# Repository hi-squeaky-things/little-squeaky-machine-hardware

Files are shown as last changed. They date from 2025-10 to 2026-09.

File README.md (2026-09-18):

```
 ⡇ ⡇⢹⠁⢹⠁⡇ ⣏⡉ ⢎⡑⡎⢱⡇⢸⣏⡉⣎⣱⣇⠜⢇⢸ ⡷⢾⣎⣱⡎⠑⣇⣸⡇⡷⣸⣏⡉
 ⠧⠤⠇⠸ ⠸ ⠧⠤⠧⠤ ⠢⠜⠣⠪⠣⠜⠧⠤⠇⠸⠇⠱ ⠇ ⠇⠸⠇⠸⠣⠔⠇⠸⠇⠇⠹⠧⠤
```
[][cc-by-nc-sa]

The Little Squeaky Machine is a hardware reference platform for the [Little Weirdo Software Synthesizer](https://github.com/hi-squeaky-things/little-weirdo). 

Our first project is launching soon: our LttL Squeaky Machine! Put yourself on the list to get notified when we are ready to ship. 

[Join the waitinglist](https://www.hi-squeaky-things.nl/waiting-list)

[cc-by-nc-sa]: https://creativecommons.org/licenses/by-nc-sa/4.0/
[cc-by-nc-sa-image]: https://licensebuttons.net/l/by-nc-sa/4.0/88x31.png
[cc-by-nc-sa-shield]: https://img.shields.io/badge/License-CC%20BY--NC--SA%204.0-lightgrey.svg

> [!CAUTION]
> This project is actively being developed with frequent breaking changes. Wires may shift, features are incomplete, and stability is not guaranteed. Use at your own risk and expect regular updates that might require SW/HW adjustments. Have fun!

> [!IMPORTANT]
> **Hi Squeaky Things** can happen at any time. _Little Squeaky Machine_ is ready to squeak, squuuueak, squeeeeeaak, squeaaaaaaaaak and drop some deep body shaking basses!

## Little Squeaky Machine Hardware

The hardware is designed using EasyEDA. 

### Revision 3.0 

We are iteration on revision 3.0. Soon to be released. 



> [!CAUTION]
Small batch of this revision is fabricated. Use the schematics and layouts at your own risk because the new design is not fully tested yet. We are testing this revision with different types of key switches and caps and color. 

Rendered versions:

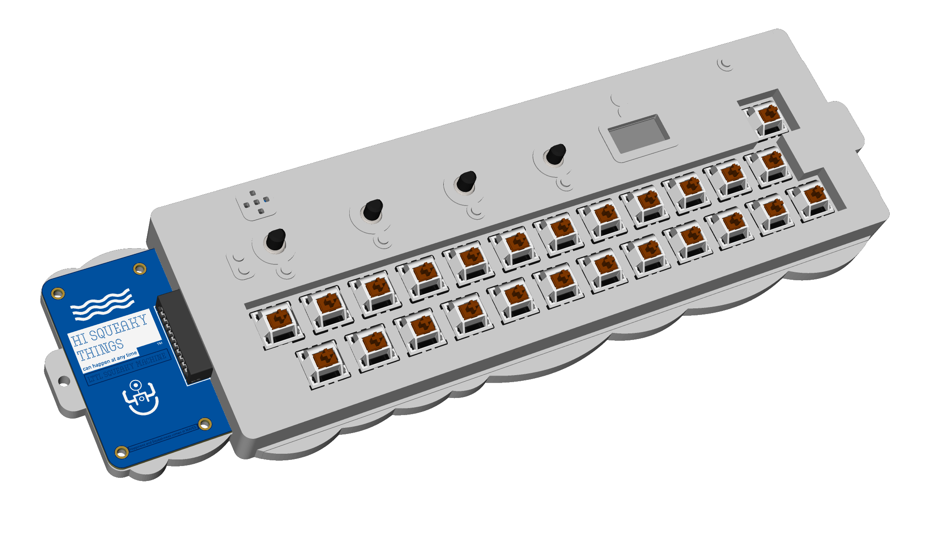
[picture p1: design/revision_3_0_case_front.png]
case front revision 3.0 with casing

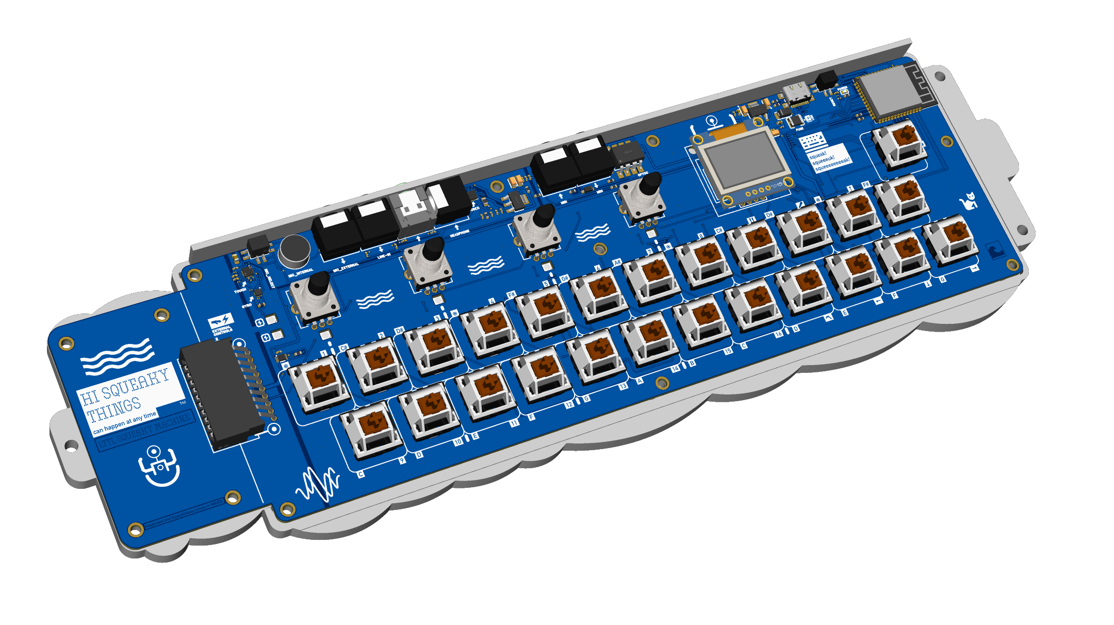
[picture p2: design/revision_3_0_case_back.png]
case back revision 3.0 with casing


- [Specification and capabilities](design/specs.md)
- [Pin layout of the ESP32S3 based MCU](design/pinout.md)
- [Fabrication files](fabrication)

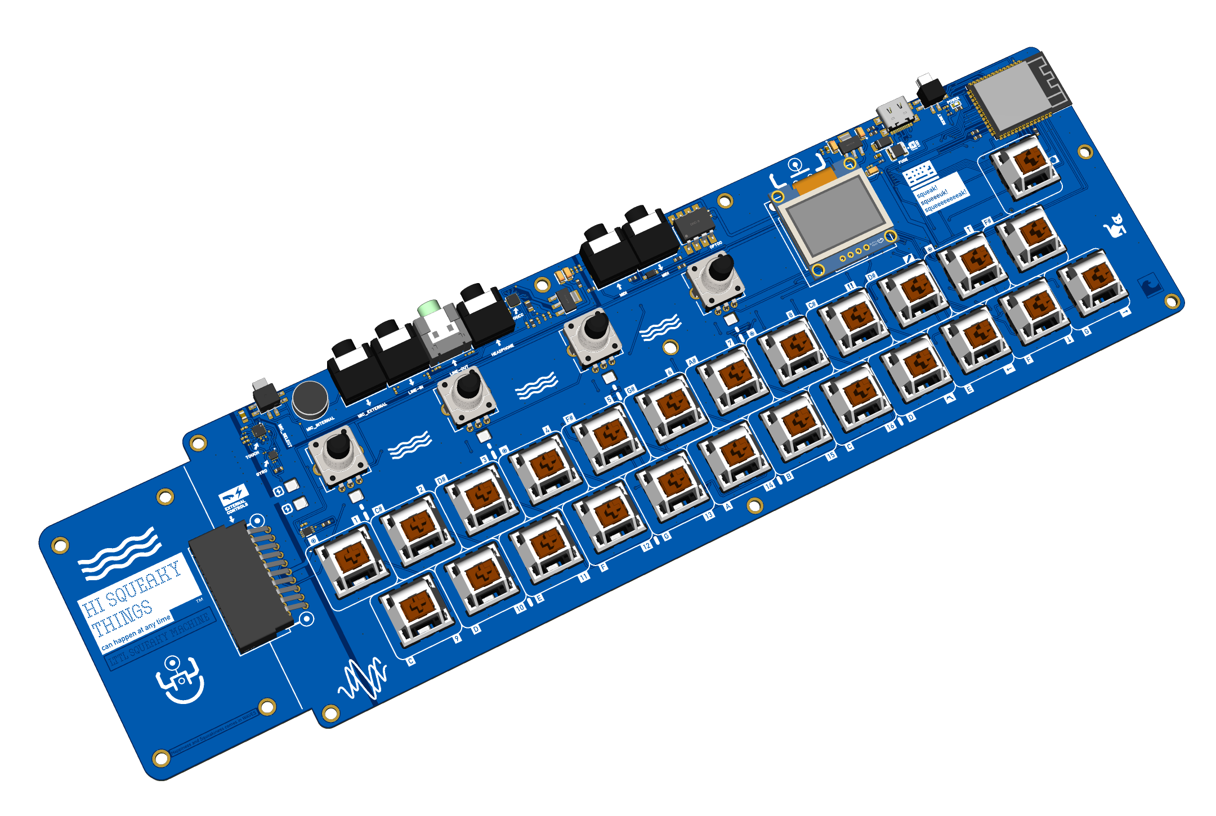
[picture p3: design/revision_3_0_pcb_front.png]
front pcb revision 2.0 pcb


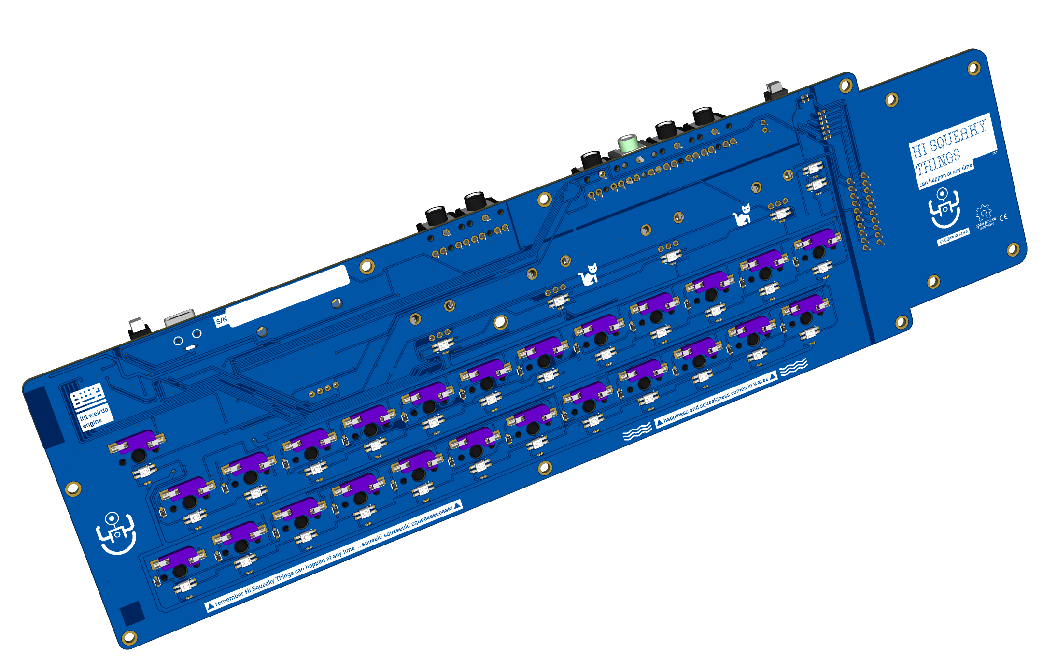
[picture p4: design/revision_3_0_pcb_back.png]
back pcb revision 2.0 pcb back


### Revision 2.0 

This is the first production ready hardware running a firmware using [Little Weirdo Software Synthesizer](https://github.com/hi-squeaky-things/little-weirdo) for sound synthesis. 

> [!CAUTION]
Small batch of this revision is fabricated. Use the schematics and layouts at your own risk because the new design is not fully tested yet. We are testing this revision with different types of key switches and caps and color. 

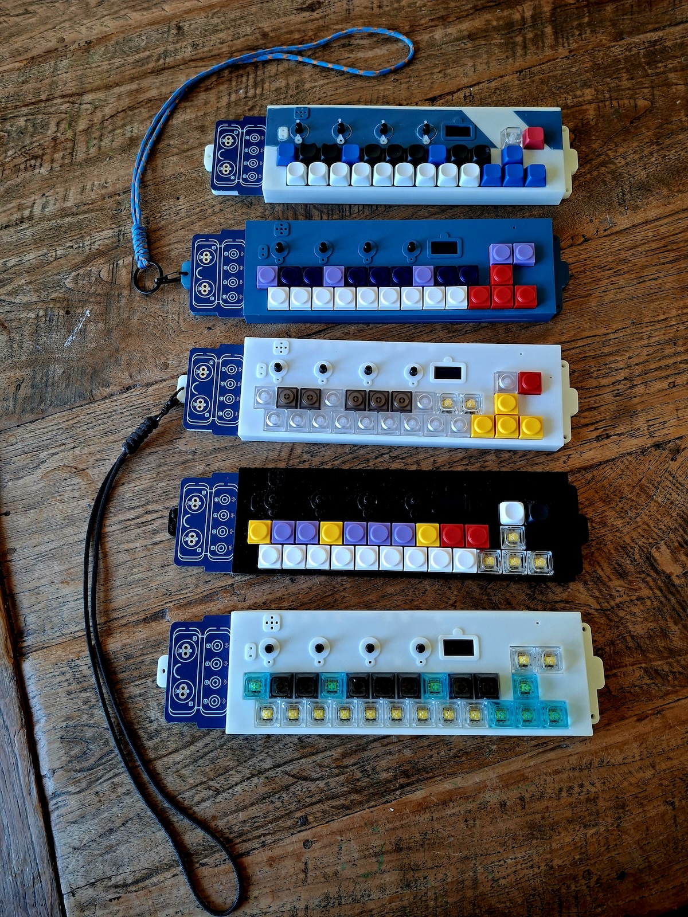
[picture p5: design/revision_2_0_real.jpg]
result assembly revision 2.0 real life


Rendered versions:

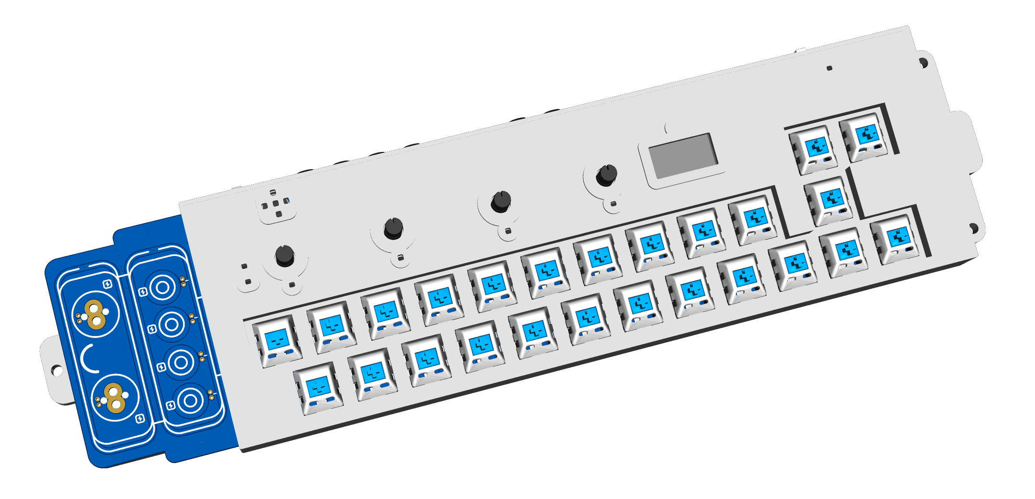
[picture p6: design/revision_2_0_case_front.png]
case front revision 2.0 with casing

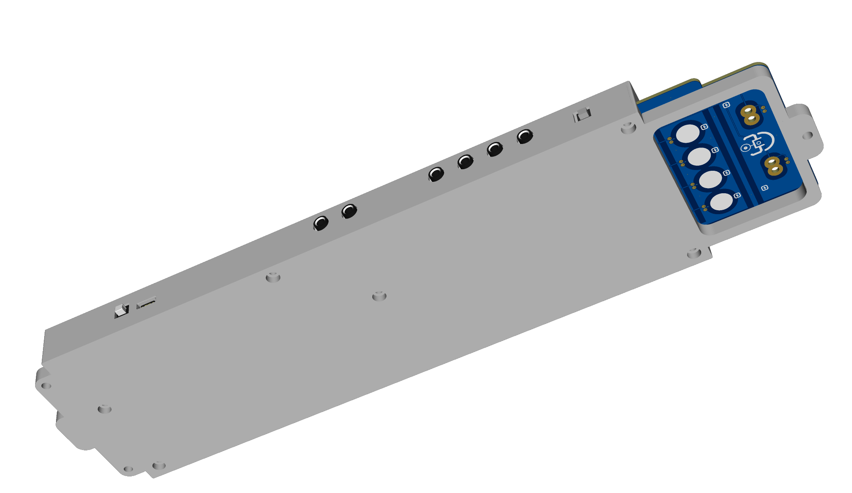
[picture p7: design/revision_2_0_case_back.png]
case back revision 2.0 with casing

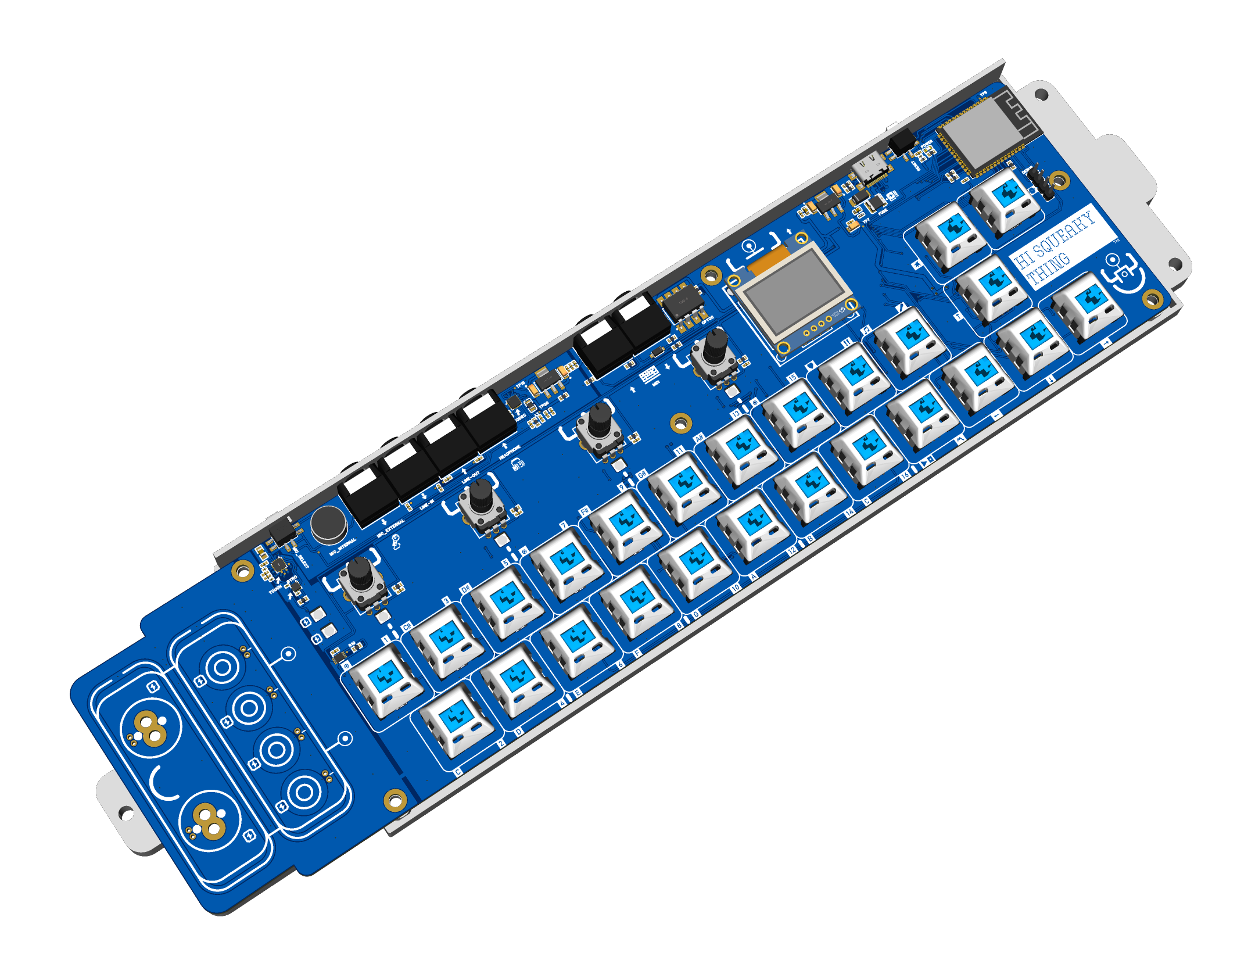
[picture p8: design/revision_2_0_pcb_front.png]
front pcb revision 2.0 pcb

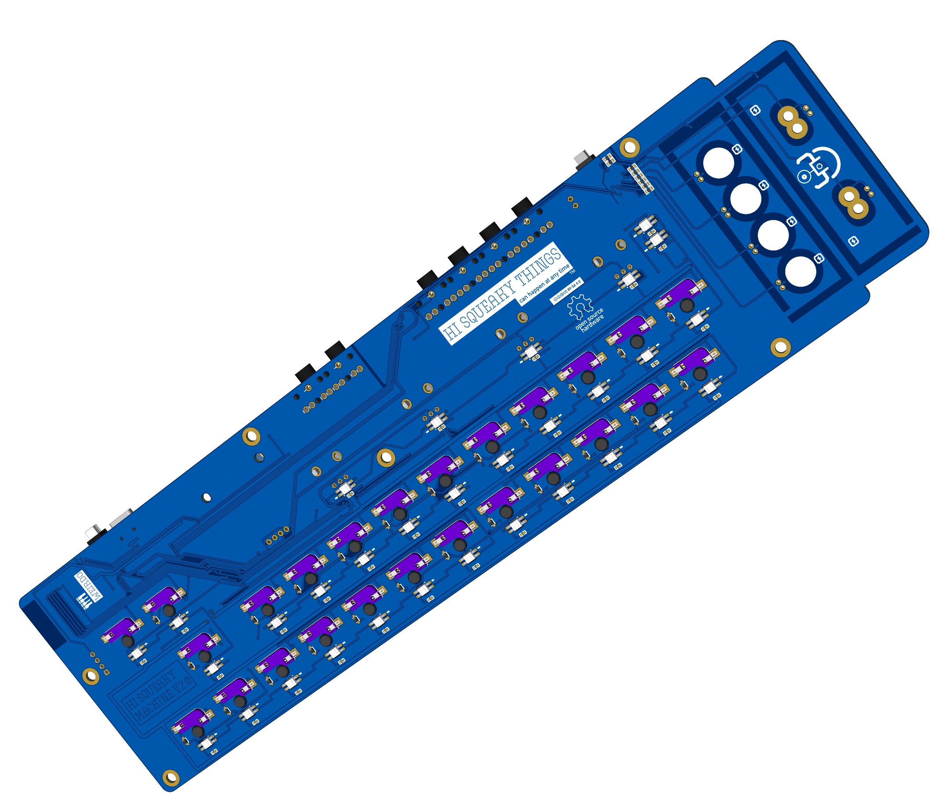
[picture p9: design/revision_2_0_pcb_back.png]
back pcb revision 2.0 pcb back


### Revision 1.0

This is the first prototype we created and running a firmware using [Little Weirdo Software Synthesizer](https://github.com/hi-squeaky-things/little-weirdo) for sound synthesis. This revision was only for a proof-of-concept some features and not for production use.

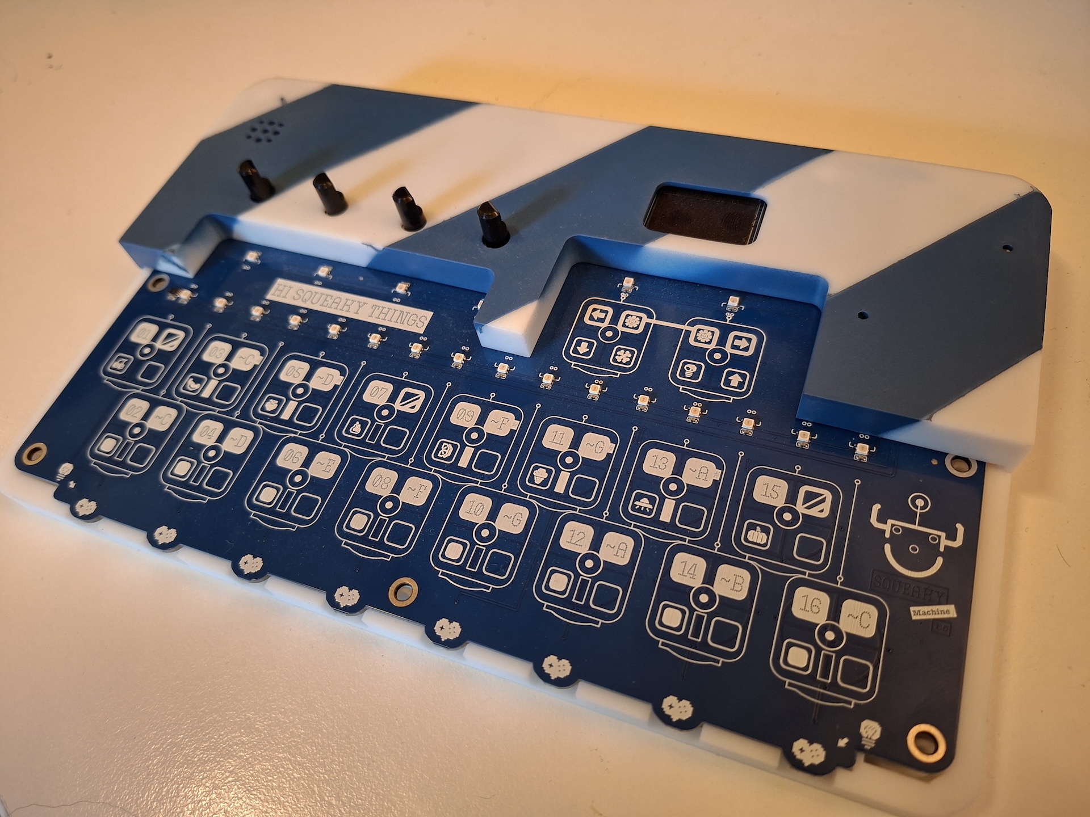
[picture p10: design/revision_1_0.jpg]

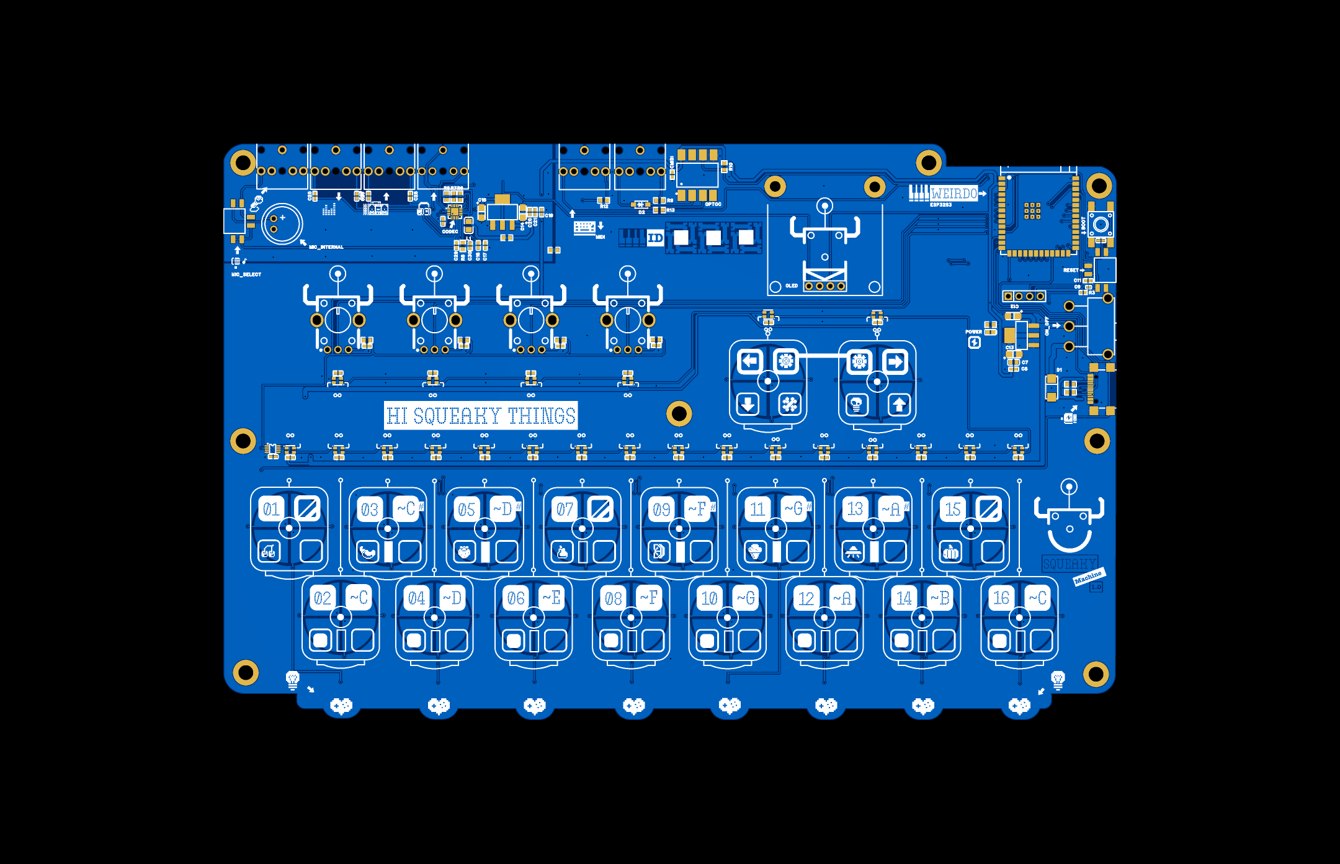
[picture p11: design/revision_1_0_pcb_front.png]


## License

This work is licensed under a
[Creative Commons Attribution-NonCommercial-ShareAlike 4.0 International License][cc-by-nc-sa].

[][cc-by-nc-sa]

## Credits

Made by Daniël, owner of Hi Squeaky Things Lab.

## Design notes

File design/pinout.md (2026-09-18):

```
 ⡇ ⡇⢹⠁⢹⠁⡇ ⣏⡉ ⢎⡑⡎⢱⡇⢸⣏⡉⣎⣱⣇⠜⢇⢸ ⡷⢾⣎⣱⡎⠑⣇⣸⡇⡷⣸⣏⡉
 ⠧⠤⠇⠸ ⠸ ⠧⠤⠧⠤ ⠢⠜⠣⠪⠣⠜⠧⠤⠇⠸⠇⠱ ⠇ ⠇⠸⠇⠸⠣⠔⠇⠸⠇⠇⠹⠧⠤
```

The Little Squeaky Machine is a hardware reference platform for the [Little Weirdo Software Synthesizer](https://github.com/hi-squeaky-things/little-weirdo).

## Little Squeaky Machine Hardware

### ESP32-S3 processing pinout

This section reflects the board-level net names as they are labeled in the processing schematic, rather than a stale hand-transcribed table. The most reliable source is the actual net names on the schematic: `EN`, `CHIP_BOOT`, `TXD0`, `RXD0`, `USB_D+`, `USB_D-`, `I2C_SDA`, `I2C_SCL`, `I2S_*`, `TOUCH_*`, `MIDI_*`, and the encoder/LED nets.

#### Core power, reset and debug

| ESP32-S3 pin | Net name | Board function |
| --- | --- | --- |
| 3 | `EN` | Chip reset / enable |
| 0 | `CHIP_BOOT` | Boot strap / boot mode |
| 1 | `RESET` | Board reset net |
| 45 | `IO45` | Unused / no board net on the current schematic |
| 46 | `IO46` | Unused / no board net on the current schematic |

#### USB and MIDI

| ESP32-S3 pin | Net name | Board function |
| --- | --- | --- |
| 19 | `USB_D-` | USB-C data minus |
| 20 | `USB_D+` | USB-C data plus |
| 17 | `MIDI_OUT` | MIDI TRS-A output |
| 18 | `MIDI_IN` | MIDI TRS-A input |

#### I2C and OLED / codec bus

| ESP32-S3 pin | Net name | Board function |
| --- | --- | --- |
| 47 | `I2C_SDA` | I2C data to OLED and codec |
| 48 | `I2C_SCL` | I2C clock to OLED and codec |

#### Audio codec I2S bus

| ESP32-S3 pin | Net name | Board function |
| --- | --- | --- |
| 42 | `I2S_MLCK` | Audio codec master clock |
| 41 | `I2S_WS` | Audio codec LRCLK / word select |
| 40 | `I2S_BCLK` | Audio codec bit clock |
| 39 | `I2S_DOUT` | Audio data out |
| 38 | `I2S_DIN` | Audio data in |

#### Touch, key matrix and controls

| ESP32-S3 pin | Net name | Board function |
| --- | --- | --- |
| 4,5,6,7,15 | `TOUCH_ROW_1` ... `TOUCH_ROW_5` | Keys rows |
| 40 | `TOUCH_COL_1` ... `TOUCH_COL_5` | Keys columns |
| 40 | `KEY_SW_25` | Key matrix switch sense for the 25-key board |
| 40 | `LED_CTRL` | LED drive signal |
| 16,8 | `ENCO0_A/B` | Encoder 0 A/B channels |
| 3,9 | `ENCO1_A/B` | Encoder 1 A/B channels |
| 1,2 | `ENCO2_A/B` | Encoder 2 A/B channels |
| 43,44 | `ENCO3_A/B` | Encoder 3 A/B channels |
| 21 | `H_OLED` | OLED header net |

#### Notes

- The schematic labels the board nets as names like `TOUCH_ROW_1`, `TOUCH_COL_1`, `I2S_WS`, `MIDI_OUT`, etc. Those net names are the most trustworthy mapping source for the actual board.
- Some ESP32-S3 GPIOs are intentionally unused in the current board design and are left as no-connects on the processing sheet.
- The design uses the ESP32-S3's native USB pins for USB-C connectivity and the UART pins for debug/boot-related lines.

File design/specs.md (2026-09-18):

```
 ⡇ ⡇⢹⠁⢹⠁⡇ ⣏⡉ ⢎⡑⡎⢱⡇⢸⣏⡉⣎⣱⣇⠜⢇⢸ ⡷⢾⣎⣱⡎⠑⣇⣸⡇⡷⣸⣏⡉
 ⠧⠤⠇⠸ ⠸ ⠧⠤⠧⠤ ⠢⠜⠣⠪⠣⠜⠧⠤⠇⠸⠇⠱ ⠇ ⠇⠸⠇⠸⠣⠔⠇⠸⠇⠇⠹⠧⠤
```

The Little Squeaky Machine is a hardware reference platform for the [Little Weirdo Software Synthesizer](https://github.com/hi-squeaky-things/little-weirdo). 

## LttL Squeaky Machine Hardware

### Specification and capabilities

| Name | Component | Function | 
| --- | --- | --- |
| Name | Component | Function |
|-------------|---------------------|------------------------------------------------------------------------------------------------------------------------|
| MCU | ESP32-S3-WROOM-1 | Running the LttL Weirdo Firmware and controlling the LttL Squeaky Machine, enabling sound generation and control through firmware. |
| CODEC | SGTL5000 | Providing advanced audio processing, including stereo line input, microphone input with bias, stereo line output, and a capless stereo headphone amplifier with mixing and filtering capabilities.  |
| TOUCH | CY8CMBR3108 | Enabling capacitive touch functionality (interface through I2C) for user interaction, suitable for applications like musical instrument controls. 8 touchpoints available through an edge connector. |
| MIDI | ESP32-S3-WROOM-1 | Facilitating MIDI data transfer through TRS-A connections, enabling communication between devices such as synthesizers and controllers. |
| USB-MIDI | ESP32-S3-WROOM-1 | Providing MIDI data transfer over USB-C connections, offering flexibility in connecting devices with USB-based interfaces. |
| ENCODER | ESP32-S3-WROOM-1 | Enabling functionality for user interaction using rotary encorders (4x). |
| GYRO | STK8321 | 3D gyroscope and x-y-z speed sensor (interface through I2C). |
| KEYS | CPG151101S11 | Hotswappable tactile switches (25x). |

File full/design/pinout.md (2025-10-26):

```
 ⡇ ⡇⢹⠁⢹⠁⡇ ⣏⡉ ⢎⡑⡎⢱⡇⢸⣏⡉⣎⣱⣇⠜⢇⢸ ⡷⢾⣎⣱⡎⠑⣇⣸⡇⡷⣸⣏⡉
 ⠧⠤⠇⠸ ⠸ ⠧⠤⠧⠤ ⠢⠜⠣⠪⠣⠜⠧⠤⠇⠸⠇⠱ ⠇ ⠇⠸⠇⠸⠣⠔⠇⠸⠇⠇⠹⠧⠤
```

The Little Squeaky Machine is a hardware reference platform for the [Little Weirdo Software Synthesizer](https://github.com/hi-squeaky-things/little-weirdo). 

## Little Squeaky Machine Hardware

### Pin layout of the MCU

| Pin ESP32-S3-WROOM-1 | Pin ESP32S3 | Function ESP32S3 | Function |
| --- | --- | --- | --- |
| 04 | 04 | TOUCH_4 | 🫳 Touchpad row 1 |
| 05 | 05 | TOUCH_5 | 🫳 Touchpad row 2 |
| 06 | 06 | TOUCH_6 | 🫳 Touchpad row 3 |
| 07 | 07 | TOUCH_7 | 🫳 Touchpad row 4 |
| 08 | 15 |  ADC2_CH4  | 🎛️ Potmeter 1 |
| 09 | 16 |  ADC2_CH5 | 🎛️ Potmeter 2 |
| 10 | 17 |  U1TXD  | 🎹 MIDI out |
| 11 | 18 |  U1RXD | 🎹 MIDI in |
| 12 | 08 |  ADC1_CH7 | 🔌 USB power management |
| 13 | 19 |  USB_D- | 💻 USB-OTG / 🎹 USB-MIDI |
| 14 | 20 |  USB_D+ | 💻 USB-OTG / 🎹 USB-MIDI |
|  |
| 15 | 03 | NC | Not connected |
| 16 | 47 | NC | Not connected |
| 17 | 09 | TOUCH_9 | 🫳 Touchpad main 1 |
| 18 | 10 | TOUCH_10 | 🫳 Touchpad main 2 |
| 19 | 11 | TOUCH_11 | 🫳 Touchpad col 4 |
| 20 | 12 | TOUCH_12 | 🫳 Touchpad col 3 |
| 21 | 13 | TOUCH_13 | 🫳 Touchpad col 2 |
| 22 | 14 | TOUCH_14 | 🫳 Touchpad col 1 |
| 23 | 21 | RMT | 💡 Led controller |
| 24 | 47 | I2C_0_SDA | I2C controller data / 📺 OLED / 🔈 CODEC  |
| 25 | 48 | I2C_1_SDL | I2C controller clock / 📺 OLED / 🔈 CODEC |
| 26 | 45 |  NC | Not connected |
|  | 
| 28 | 35 | NC | Not connected |
| 29 | 36 | NC | Not connected |
| 30 | 37 | NC | Not connected |
| 31 | 38 | I2S_0_MLCK | I2S controller, master clock (MLCK) / 🔈 CODEC|
| 32 | 39 | I2S_0_WS | I2S controller, word select (LRCLK) / 🔈 CODEC |
| 33 | 40 | I2S_0_BLCK | I2S controller, block select (BLCK) / 🔈 CODEC |
| 34 | 41 | I2S_0_DIN | 🔈 I2S controller, data IN (DIN) / 🔈 CODEC |
| 35 | 42 | I2S_0_DOUT | 🎤 I2S controller, data OUT (DOUT) / 🔈 CODEC |
| 36 | 44 | U0RXD | Firmware TX / JTAG / Serial Debug |
| 37 | 43 | U0TXD| Firmware RX / JTAG / Serial Debug |
| 38 | 02 |  ADC1_CH1  | 🎛️ Potmeter 4 |
| 39 | 01 |  ADC1_CH0 | 🎛️ Potmeter 3 |
|

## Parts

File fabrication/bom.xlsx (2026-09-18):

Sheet: bom模板
 |  |  |  | Bill of Materials | BOM_Little_Squeaky_Machine_Main_Little Squeaky Machine_2026-09-15
 |  |  |  | Project Title： | little_squeaky_machine_V3
 |  |  |  | Variant:
 |  |  |  | Report Time： | 2026年9月15日 22:30:16
No. | Quantity | Comment | Designator | Footprint | Value | Manufacturer Part | Manufacturer | Supplier Part | Supplier | LCSC Price | Total
 | 1 | 10uF | C7 | C0603 | 10uF | CGA0603X5R106K100JT | HRE(芯声) | C6119842 | LCSC
 | 43 | 100nF | C8, C11, C16, C17, C20, C21, C29, C38, C39, C41, C45, CLED1, CLED2, CLED3, CLED4, CLED5, CLED6, CLED7, CLED8, CLED9, CLED10, CLED11, CLED12, CLED13, CLED14, CLED15, CLED16, CLED17, CLED18, CLED19, CLED20, CLED21, CLED22, CLED23, CLED24, CLED25, CLED26, CLED27, CLED28, CLED29, CLED30, CLED31, CMIDI | C0402 | 100nF | CL05B104KO5NNNC | SAMSUNG(三星) | C1525 | LCSC
 | 5 | 1uF | C9, C35, C36, C37, C40 | C0201 | 1uF | GRM033R61A105ME44D | muRata(村田) | C76935 | LCSC
 | 3 | 10uF | C12, C14, C44 | CASE-A_3216 | 10uF | CA45-A010M106T | 湘怡中元/湘江 | C127946 | LCSC
 | 2 | 22uF | C13, C15 | CASE-A_3216 | 22uF | CA45-A-10V-22uF-K | CEC(振华新云) | C129272 | LCSC
 | 7 | 2.2uF | C18, C19, C25, C26, C27, C28, C30 | C0402 | 2.2uF | CGA0402X5R225M6R3GT | HRE(芯声) | C7503516 | LCSC
 | 1 | 150nF | C22 | C0402 | 150nF | TCC0402X7R154K160AT | CCTC(三环) | C7393865 | LCSC
 | 1 | 2.2nF | C43 | C0805 | 2.2nF | CL21C222JBFNNNE | SAMSUNG(三星) | C28260 | LCSC
 | 1 | 10nF | C46 | C0603 | 10nF | CGA0603X7R103M500JT | HRE(芯声) | C36911427 | LCSC
 | 1 | SGTL5000XNLA3R2 | CODEC | QFN-20_L3.0-W3.0-P0.40-BL-EP1.7 |  | SGTL5000XNLA3R2 | NXP(恩智浦) | C2651833 | LCSC
 | 1 | SS34 | D1 | SMA_L4.3-W2.6-LS5.2-RD |  | SS34 | MDD(辰达半导体) | C8678 | LCSC
 | 1 | 1N914W | D2 | SOD-123_L2.7-W1.6-LS3.7-RD-1 |  | 1N914W | CBI(创基) | C2836060 | LCSC
 | 1 | X2549WR-2x10A-PTV01 | EDGE_CONNECTOR | CONN-TH_20P-P2.54_X2549WR-2X10A-PTV01 |  | X2549WR-2x10A-PTV01 | XKB Connection(中国星坤) | C21261721 | LCSC
 | 4 | EC12E24404A8 | ENCO0, ENCO1, ENCO2, ENCO3 | SW-TH_EC12EXXXX |  | EC12E24404A8 | ALPSALPINE(阿尔卑斯阿尔派) | C470600 | LCSC
 | 1 | ESP32-S3-WROOM-1-N16R8 | ESP32S3 | WIRELM-SMD_ESP32-S3-WROOM-1 |  | ESP32-S3-WROOM-1-N16R8 | ESPRESSIF(乐鑫) | C2913202 | LCSC
 | 1 | SMD1812-300C-16V | FUSE | F1812 |  | SMD1812-300C-16V | BNstar(比诺星) | C2760295 | LCSC
 | 1 | STK8321 | GYRO | LGA-12_L2.0-W2.0-P0.50-TR |  | STK8321 | SENSORTEK(昇佳) | C966924 | LCSC
 | 1 | PJ-3062-CO | HEADPHONE | AUDIO-TH_PJ-3062-HD-B |  | PJ-3062-CO | XKB Connection(中国星坤) | C319113 | LCSC
 | 25 | CPG151101S11-16 | KEY_1, KEY_2, KEY_3, KEY_4, KEY_5, KEY_6, KEY_7, KEY_8, KEY_9, KEY_10, KEY_11, KEY_12, KEY_13, KEY_14, KEY_15, KEY_16, KEY_17, KEY_18, KEY_19, KEY_20, KEY_21, KEY_22, KEY_23, KEY_24, KEY_25 | SMD_KEYBOARD-SW |  | CPG151101S11-16 | HanElectricity(瀚源) | C41430893 | LCSC
 | 24 | 1N4148WS | KEY_D1, KEY_D2, KEY_D3, KEY_D4, KEY_D5, KEY_D6, KEY_D7, KEY_D8, KEY_D9, KEY_D10, KEY_D11, KEY_D12, KEY_D13, KEY_D14, KEY_D15, KEY_D16, KEY_D17, KEY_D18, KEY_D19, KEY_D20, KEY_D21, KEY_D22, KEY_D23, KEY_D24 | SOD-323_L1.8-W1.3-LS2.5-RD |  | 1N4148WS | Hottech(合科泰) | C181133 | LCSC
 | 1 | HCB2012KV-601T20 | L1 | L0805 |  | HCB2012KV-601T20 | TAI-TECH(台庆) | C5139902 | LCSC
 | 1 | BLM15PX330SN1D | L2 | L0402 |  | BLM15PX330SN1D | muRata(村田) | C160974 | LCSC
 | 1 | AMS1117-3.3 | LDO | SOT-223-4_L6.5-W3.5-P2.30-LS7.0-BR |  | AMS1117-3.3 | UMW(友台半导体) | C347222 | LCSC
 | 31 | SK6812MINI-E | LED1, LED2, LED3, LED4, LED5, LED6, LED7, LED8, LED9, LED10, LED11, LED12, LED13, LED14, LED15, LED16, LED17, LED18, LED19, LED20, LED21, LED22, LED23, LED24, LED25, LED26, LED27, LED28, LED29, LED30, LED31 | LED-SMD_4P-L3.2-W2.8-LS5.9_SK6812MINI-E |  | SK6812MINI-E | 欧思科光电 | C5149201 | LCSC
 | 2 | PJ-3062-HD-R | LINE-IN, MIC_EXTERNAL | AUDIO-TH_PJ-3062-HD-B |  | PJ-3062-HD-R | XKB Connection(中国星坤) | C668225 | LCSC
 | 1 | PJ-3062-HD-G | LINE-OUT | AUDIO-TH_PJ-3062-HD-B |  | PJ-3062-HD-G | XKB Connection(中国星坤) | C431042 | LCSC
 | 1 | KEAG4544PF-K | MIC_INTERNAL | MIC-TH_BD9.7-P2.50-D0.8-L-FD |  | KEAG4544PF-K | KINGSTATE(志丰电子) | C7430174 | LCSC
 | 1 | XKB5858-Z-F-75 | MIC_SELECT | SW-SMD_XKB5858-Z-F-75 |  | XKB5858-Z-F-75 | XKB Connection(中国星坤) | C2884736 | LCSC
 | 2 | PJ-3062-HD-B | MIDI-IN, MIDI-OUT | AUDIO-TH_PJ-3062-HD-B |  | PJ-3062-HD-B | XKB Connection(中国星坤) | C692443 | LCSC
 | 1 | HS96L03W2C03 | OLED | OLED-TH_L27.8-W27.2-P2.54_C9900033791 |  | HS96L03W2C03 | HS(汉昇) | C5248080 | LCSC
 | 1 | 6N137S1(TA) | OPTOC | SMD-8_L9.8-W6.6-P2.54-LS10.3-BL |  | 6N137S1(TA) | EVERLIGHT(亿光) | C110020 | LCSC
 | 1 | F.0603.00025/P2-0603G1TS2-06T-002 | POWER | LED0603-RD_GREEN |  | F.0603.00025/P2-0603G1TS2-06T-002 | TUOZHAN(拓展光电) | C7496818 | LCSC
 | 2 | 5.1kΩ | R1, R2 | R0603 | 5.1kΩ | 0603WAF5101T5E | UNI-ROYAL(厚声) | C23186 | LCSC
 | 1 | 10kΩ | R3 | R0402 | 10kΩ | SCR0402J10K | VO(翔胜) | C3017497 | LCSC
 | 1 | 1kΩ | R4 | R0603 | 1kΩ | FRC0603J102 TS | FOJAN(富捷) | C2907113 | LCSC
 | 3 | 2.2kΩ | R5, R6, R8 | R0603 | 2.2kΩ | 0603WAF2201T5E | UNI-ROYAL(厚声) | C4190 | LCSC
 | 1 | 100Ω | R7 | R0603 | 100Ω | RC0603FR-07100RL | YAGEO(国巨) | C105588 | LCSC
 | 1 | 220Ω | R9 | R0603 | 220Ω | SCR0603J220R | VO(翔胜) | C3017752 | LCSC
 | 1 | 470Ω | R10 | R0603 | 470Ω | SCR0603F470R | VO(翔胜) | C5140094 | LCSC
 | 1 | 33Ω | R12 | R0603 | 33Ω | 0603WAF330JT5E | UNI-ROYAL(厚声) | C23140 | LCSC
 | 1 | 10Ω | R13 | R0603 | 10Ω | QR0603J10R0P05Z | EVER OHMS(天二科技) | C176153 | LCSC
 | 1 | 22Ω | R18 | R0603 | 22Ω | 0603WAF220JT5E | UNI-ROYAL(厚声) | C23345 | LCSC
 | 9 | 500Ω | R19, R20, R21, R22, R23, R24, R25, R26, R27 | R0603 | 500Ω | RT0603BRD07500RL | YAGEO(国巨) | C6207671 | LCSC
 | 1 | XKB5858-W-F-75 | RESET | SW-SMD_XKB5858-W-F-75 |  | XKB5858-W-F-75 | XKB Connection(中国星坤) | C780037 | LCSC
 | 1 | CY8CMBR3108-LQXI | TOUCH | QFN-16_L3.0-W3.0-P0.50-BL-EP1.7 |  | CY8CMBR3108-LQXI | Infineon/CYPRESS(赛普拉斯) | C511139 | LCSC
 | 1 | AMS1117-1.8 | U1 | SOT-223_L6.7-W3.5-P2.30-BR |  | AMS1117-1.8 | UMW(友台半导体) | C347220 | LCSC
 | 1 | GT74LVC2T45V8 | U2 | VSSOP-8_L2.3-W2.0-P0.50-LS3.1-BL |  | GT74LVC2T45V8 | GTIC(谷泰微) | C22356905 | LCSC
 | 1 | TYPEC-304YSSW-ACP16 | USB | USB-SMD_TYPEC-304YSSW-ACP16 |  | TYPEC-304YSSW-ACP16 | XUNPU(讯普) | C2840392 | LCSC

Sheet: Field汇总
Project Title | little_squeaky_machine_V3
Borard Title | Little_Squeaky_Machine_Main
Schematic Title | Little Squeaky Machine
PCB Title | Little Squeaky Machine
Variant Name
Total Quantity | 237
Report Time | 22:30:16
Report Date | 2026年9月15日
Report Date&Time | 2026年9月15日 22:30:16
File Name | BOM_Little_Squeaky_Machine_Main_Little Squeaky Machine_2026-09-15
Filter Option | Add into BOM:no;

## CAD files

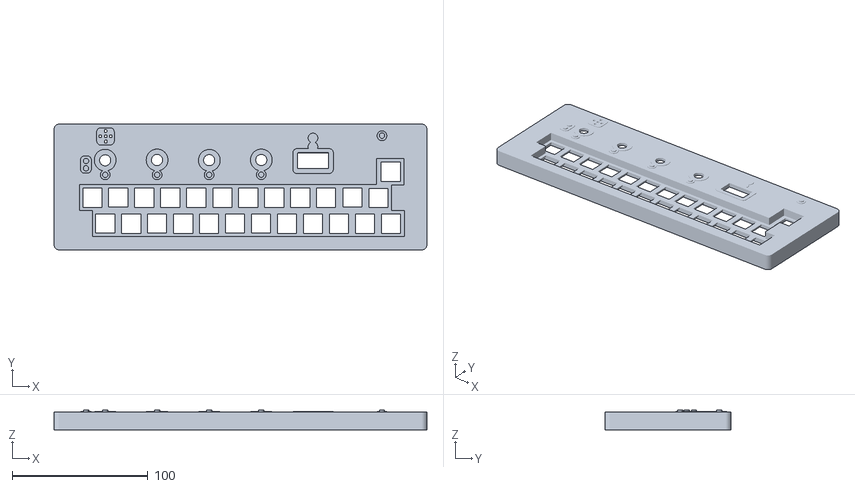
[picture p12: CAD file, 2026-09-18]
fabrication/top.stl
274.5 x 92.7 x 14.5

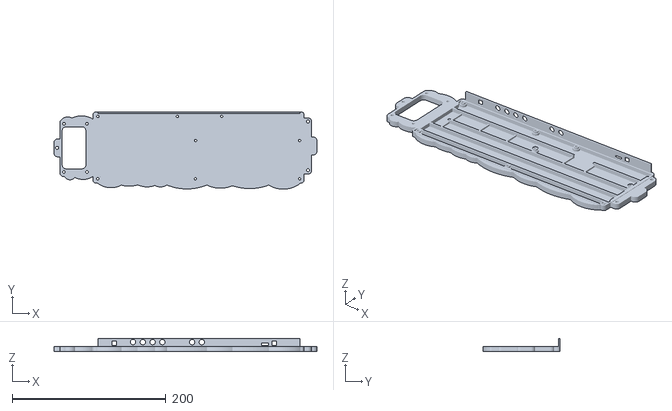
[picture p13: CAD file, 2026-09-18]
fabrication/bottom.stl
341.9 x 100.6 x 17.5

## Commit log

2026-02-17 update to pre-release v2.0
    [BOM_Little_Squeaky_Machine_Hardware_Little Squeaky Machine_2026-02-17.xlsx, PickAndPlace_Little Squeaky Machine_2026-02-17.xlsx]
2026-02-19 update to latest revision
    [BOM_Little_Squeaky_Machine_Hardware_Little Squeaky Machine_2026-02-17.xlsx, PickAndPlace_Little Squeaky Machine_2026-02-17.xlsx, bom.xlsx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]
2026-09-18 Update production files and documentation for version 3.0 (#1)
    * update to production files for version 3.0
    * update documentation
    * update 3d shell
    * Remove outdated references to revision 2.0 and clean up README formatting
    [bom.xlsx, bottom.stl, pickandplace.xlsx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]

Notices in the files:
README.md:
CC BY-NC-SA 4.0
